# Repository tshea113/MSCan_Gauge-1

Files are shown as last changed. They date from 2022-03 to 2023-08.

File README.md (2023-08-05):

MSCan_Gauge
===========

This project uses a [Teensy 3.2 or 4.0 microcontroller](https://www.pjrc.com/teensy/index.html) to interface with a [Megasquirt open source standalone
engine controller](http://www.msextra.com/) via CAN bus. Data is received from the ECU and shown on a display that fits in a standard 52mm gauge pod.

Due to Teensy 3.2 availability, the project has been ported to work with [Teensy 4.0](https://www.pjrc.com/store/teensy40.html) which is both more powerful and more available. Highly suggest using that hardware over the Teensy 3.2.

## Demo
https://youtube.com/shorts/4NsZm0GjasA?feature=share

## Hardware used
* [Teensy 4.0 microcontroller](https://www.pjrc.com/store/teensy40.html)
* [Adafruit 128x64 monochrome 1.3" OLED display](http://www.adafruit.com/products/938) connected via SPI.
* [Adafruit rotary encoder](http://www.adafruit.com/products/377)

Unfortunately this display from Adafruit is pretty expensive compared to some of the cheaper no-name brands.
The gauge housing is fitted to work with this specific display model, but, although untested, any one of the SSD1306 driver controlled displays should work (as long as the screen is 128x64 pixels).

The rotary encoder is P/N: PEC11-4215F-S24 (or any substituteable encoder). If you are already ordering from Adafruit, it's best to just grab theirs.

## Libraries required
* [Metro](https://github.com/thomasfredericks/Metro-Arduino-Wiring) - event scheduling
* [Time](https://github.com/PaulStoffregen/Time) - onboard clock
* [FlexCAN_T4](https://github.com/tonton81/FlexCAN_T4) - CAN bus
* [SSD1306](https://github.com/adafruit/Adafruit_SSD1306) - OLED display
* [Adafruit GFX](https://github.com/adafruit/Adafruit-GFX-Library) - required by SSD1306
* [Adafruit BusIO](https://github.com/adafruit/Adafruit_BusIO) - I2C and SPI library (required by SSD1306)
* [EncoderTool](https://github.com/luni64/EncoderTool) - rotary encoder
* [Bounce2](https://github.com/thomasfredericks/Bounce2) - button debouncing

## Component BOM
Passives are 1206 package unless otherwise noted.
* R1 - 10K
* C1 - 10uF
* IC1 - SN65HVD230 (or similar) CAN transceiver
* VR1 - TSR 1-2450 DC/DC Converter (500mA may work but 1A is recommended)
* 2.54mm spacing male pin headers - standard length (5 male pins for OLED screen and 4 male pins for encoder)
* 2.54mm spacing female socket headers - standard length (2 banks of 14 female pins for the teensy)
* 8 way Molex Micro-fit+ connectors (Cable mount male and PCB mount female) and associated pins
* 5 and 4 position mating headers or connectors for OLED screen and encoder connections respectively

## Building the device

There are a lot of individual pieces that come together in this project, so it is best to test things as much as you can each step of the way. The gauge should come on when plugged into USB while external power is disconnected.
Before setting up CAN in your car, the gauge should still come on when the car is powered on and display a message about waiting for data. When you set up the CAN connection, you should start to see data come in on the screen.

### Software
You can use the released software to get a known working stable version. Install Teensyduino on your system and load the supplied hex file for your device. Plug in the teensy to your computer and press the program button on the Teensy and the software should be programmed.

If you would like to modify the code, you can build it yourself through Arduino IDE. You will need to install the listed libraries before building.

### PCB
Board gerber files are stored under Board files. Teensy 3.2 and Teensy 4.0 are *NOT* pin compatible, so choose the right PCB for your Teensy. Then encoder files are just for the rotary encoder which will be mounted remotely. I used OSHPark to build my boards, but there are plenty of PCB fabs out there to use.

The component BOM matches the labels on the PCB. You should be able to solder everything using a fine tip soldering iron. The CAN tranceiver is a little tricky, but doable.

### Housing
Highly recommended to print these out of ABS/ASA. I used PLA as a prototype and it *WILL* deform. Print the main housing using supports, but the PCB tray and the face should be able to just print flat on the print bed.

You will need the following fasteners:
* 8 M2 nuts
* 4 M2 bolts 6mm length
* 4 M2 bolts 10mm length

Fasten the PCB to the tray by placing 4 of the M2 nuts in the slots on the bottom. Use the shorter 6mm bolts to secure the PCB. The tray should slide right into the housing with the Molex connector coming out the back.
The tray may be tight at first, but sliding it in and out a few times should clearance it enough to be smooth.

Place 4 of the M2 Nuts into the back of the holes for the display mounts. Use a bolt to pull the nuts into their slots. Once they are in, they should be secure enough that they do not fall out.

To connect the display, you will need 5 female-to-female connectors. I used some pre-made 3 inch wires that have female header pins on the ends. Tuck the wires back into the gauge and place the screen into the slot.
Secure the display using the 10mm bolts. The gauge face should slot right into the housing.

### Car wiring
The wiring in the car should be wired up to the male Micro-fit+ connector. You will need to supply:
* 12V power
  * Preferably something that isn't hot while cranking.
  * This will probably be the same supply you use for other gauges like wideband.
* Ground
  * Nothing specific here, this isn't a sensor ground or anything.
* ENCG
  * This is the ground for the encoder. It should wire up to the corresponding pin on the encoder PCB.
* ENCB
  * This is the button pin for the encoder. It should wire up to the corresponding pin on the encoder PCB.
* ENC1
  * This is one of the direction pins for the encoder. It should wire up to the corresponding pin on the encoder PCB.
* ENC2
  * This is the other direction pin for the encoder. It should wire up to the corresponding pin on the encoder PCB.
* CANL
  * CAN low signal. This should wire up to the MegaSquirt.
* CANH
  * CAN high signal. This should wire up to the MegaSquirt.

CANL and CANH wires are a differential signal and should be twisted together coming from the ECU to whatever device you are connecting them to (in this case the gauge).

The CAN bus requires a 120Ohm termination at the end of the bus. I did not include this on the gauge, since other devices may already have this termination.
If this gauge is your only CAN device, you can use a Deutsh connector with this termination on the end:
* DTM06-2S-P006
  * This is the 120Ohm termination
* DTM04-2P
  * This is the female receptical.
  * You will also need pins and the little plastic bracket. Read more on Deutsch connectors to see what parts you need.

The Molex Micro-fit+ pins are very small and delicate. They do not require any special crimping tools, and I was able to use a generic pin crimping tool without issues. The pins should slot into the male housing and you will feel a click when they are secure.
If you aren't gentle with them, the wings on the end that secure the pins will get bent. To fix this, pull out the pin, carefully bend the wings back, and try again.

Connect the Molex connector to the gauge, and the gauge should come on when the ignition is in the ON position.

### Tunerstudio
You will need to configure CAN Realtime Data Broadcasting for the data you are interested in.
* Make sure the baseID is set to 1520.
* Data rate for each item will depend on how fast you expect the data to change. Things like coolant temp and MAT are going to be very slow while things like RPM and MAP are going to be faster.
* Be sure the master enable for CAN is set under CAN Paramteters
* Also enable CAN Broadcasting under CAN Broadcasting

## Future Development

There probably won't be any development on this project outside of bug fixes to make sure this stays in a good state.
I'm working on a new project that will allow me to fix some of the headaches with this design:
* Updating the diplay to use the GC9A01A circular LCD display.
  * LCDs are much easier to see in the sunlight and this display has RGB colors.
* Changing the project to use PlatformIO
  * This will allow the project to store libraries in GitHub. You will be able to sync the repo and build it directly!
  * I can use GitHub Actions to automate builds in the repo.
  * Lots of nice tools inside of PlatformIO IDE.
* Moving away from the Arduino style coding to something more C++ based.
  * Partially enabled by PlatformIO, since it just builds using CMake.
  * This project grew in scope enough where the lack of OOP was making it difficult to manage data & states.

New development will be under the teensy-CAN-gauge project: https://github.com/tshea113/teensy-CAN-gauge/

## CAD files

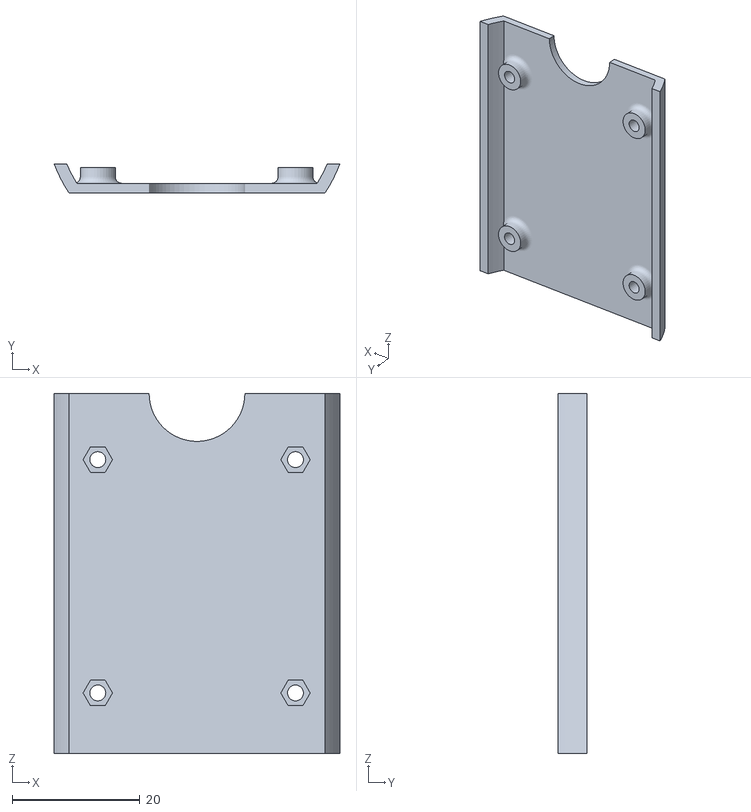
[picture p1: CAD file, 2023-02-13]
Housing files/PCB Plate.stl
44.8 x 4.50 x 56.4

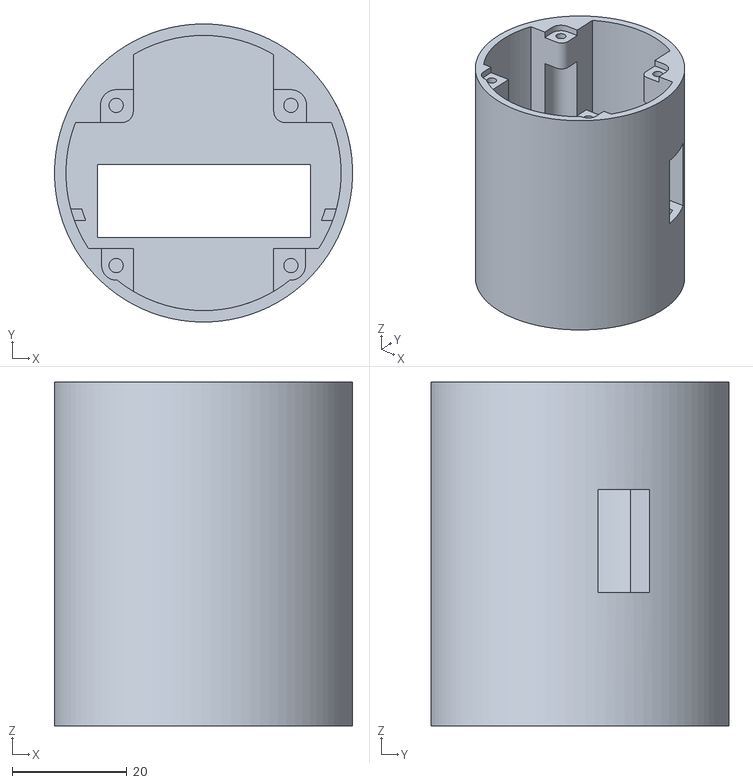
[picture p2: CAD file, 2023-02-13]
Housing files/Gauge Body.stl
52.0 x 52.0 x 60.0

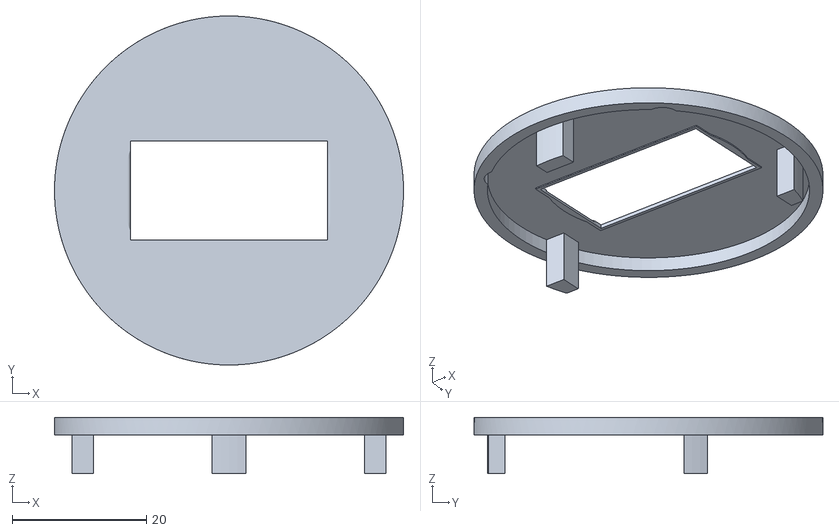
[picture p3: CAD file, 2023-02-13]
Housing files/LCD Faceplate.stl
52.0 x 52.0 x 8.40

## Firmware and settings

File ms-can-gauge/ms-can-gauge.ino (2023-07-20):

#include <Metro.h>
#include <FlexCAN_T4.h>
#include <Wire.h>
#include <Adafruit_GFX.h>
#include <Adafruit_SSD1306.h>
#include <TimeLib.h>
#include <EncoderTool.h>
#include <EEPROM.h>
#include <Bounce2.h>

#include "megasquirt-messages.h"
#include "pin-definitions.h"
#include "constants.h"
#include "gauge-data.h"

using namespace EncoderTool;

// Encoder
Encoder myEncoder;
Bounce2::Button encoderButton;
int encoder_index;

// FlexCAN
// Teensy 3.2 only has CAN0, but Teensy 4.0 has CAN1, CAN2, and CAN3, so we must
// set these up based upon the device for which we are compiling.
#if defined(__MK20DX256__) || defined(__MK64FX512__) // Teensy 3.2/3.5
  FlexCAN_T4<CAN0, RX_SIZE_256, TX_SIZE_16> myCan;
#endif
#if defined(__IMXRT1062__) // Teensy 4.0
  FlexCAN_T4<CAN2, RX_SIZE_256, TX_SIZE_16> myCan;
#endif

// OLED Display I2C
Adafruit_SSD1306 display(kOledWidth, kOledHeight, &Wire, OLED_RESET);

// Metro ticks are milliseconds
Metro commTimer = Metro(kCanTimeout);
Metro displayTimer = Metro(kDisplayRefresh);
boolean connection_state = false;

// MS data vars
GaugeData gaugeData;

// Menu vars
MenuState menuState;
Settings gaugeSettings;

static CAN_message_t txMessage,rxMessage;

msg_packed rxmsg_id,txmsg_id;
msg_req_data_raw msg_req_data;

unsigned long validity_window_highest; // for hi/low + histogram window update
unsigned long validity_window_lowest;

int histogram[64];
int histogram_index;

// -------------------------------------------------------------
void setup(void)
{
  // By default, we'll generate the high voltage from the 3.3v line internally! (neat!)
  display.begin(SSD1306_SWITCHCAPVCC, kScreenI2cAddress);

  // Show splashscreen
  display.clearDisplay();
  display.drawBitmap(0,0, miata_logo, 128, 64, 1);
  display.display();

  // On first run of the gauge, the EEPROM will have garbage values. To fix this,
  // we check that all values are written before starting.
  if (EEPROM.read(kEEPROMInitAddr) != kEEPROMValidId)
  {
    for(int i = EEPROM.read(kEEPROMInitAddr); i <= kEEPROMValidId; i++)
    {
      switch (i)
      {
      default:
        EEPROM.write(kWarningEnableAddr, gaugeSettings.warnings_enable);
        break;
      case 1:
        EEPROM.write(kCoolantWarningAddr, gaugeSettings.coolant_warning_temp);
        EEPROM.write(kCoolantWarningAddr + 1, gaugeSettings.coolant_warning_temp >> 8);
        break;
      }
    }
    EEPROM.write(kEEPROMInitAddr, kEEPROMValidId);
  }

  gaugeSettings.warnings_enable = EEPROM.read(kWarningEnableAddr);
  gaugeSettings.coolant_warning_temp = EEPROM.read((kCoolantWarningAddr + 1)) << 8;
  gaugeSettings.coolant_warning_temp |= EEPROM.read(kCoolantWarningAddr);

  if (kDebugMode)
  {
    Serial.print("Warnings Enable: ");
    Serial.println(gaugeSettings.warnings_enable);
    Serial.print("Coolant Warning: ");
    Serial.println(gaugeSettings.coolant_warning_temp);
  }

  myCan.begin();
  myCan.setBaudRate(kCanBaud);

  myEncoder.begin(ENC_PIN_1, ENC_PIN_2);
  encoderButton.attach(ENC_BUTTON, INPUT_PULLUP);
  encoderButton.interval(kButtonInterval);
  encoderButton.setPressedState(LOW);

  pinMode(LED_BUILTIN, OUTPUT);
  digitalWrite(LED_BUILTIN, HIGH);
  delay(500);
  digitalWrite(LED_BUILTIN, LOW);
}

// -------------------------------------------------------------
void loop(void)
{
  encoderButton.update();
  MenuCheck();

  // See if we have gotten any CAN messages in the last second. display an error if not
  if (commTimer.check() && !kDebugMode)
  {
    display.clearDisplay();
    display.setTextSize(1);
    display.setTextColor(WHITE);
    display.setCursor(0,56);
    display.println("Waiting for data...");
    display.setCursor(0,0);
    display.display();

    commTimer.reset();
    connection_state = false;
  }

  // main display routine
  if ((connection_state || kDebugMode) && displayTimer.check())
  {
    if (menuState.in_menu)
    {
      MenuView();
    }
    else if (menuState.in_settings)
    {
      SettingsView();
    }
    else
    {
      if (IsOutOfBounds() && gaugeSettings.warnings_enable)
      {
        WarningView();
      }
      else
      {
        switch (static_cast<ViewsMenu>(menuState.menu_position))
        {
        case kDashboardView:
          DashboardView();
          break;
        case kSingleView:
          SingleView();
          break;
        case kGraphView:
          GraphView();
          break;
        default:
          Serial.println("Invalid view!");
        }
      } 
    }
    display.display();
    displayTimer.reset();
  }

  // handle received CAN frames
  if (myCan.read(rxMessage) && !kDebugMode)
  {
    commTimer.reset();
    connection_state = true;

    ReadCanMessage();
  }
}

// Converts a value stored in the format (val)E-1 to a decimal string for display
String ToDecimal(int val)
{
  String temp = String(val);

  // Single digit values need a leading zero
  if (temp.length() == 1)
  {
    return "0." + temp.substring(0, temp.length());
  }
  else
  {
    return temp.substring(0, temp.length() - 1) + '.' + temp.charAt(temp.length() - 1);
  }
}

// Returns the number of characters in an integer
int IntegerWidth(int val, bool isDecimal)
{
  String temp = String(val);
  if (isDecimal)
  {
    // Single digit values need a leading zero
    if (temp.length() == 1)
    {
      return temp.length() + 2;
    }
    else
    {
      return temp.length() + 1;
    }
  }
  else
  {
    return temp.length();
  }
}

void ReadCanMessage()
{
  // ID's 1520+ are Megasquirt CAN broadcast frames
  switch (rxMessage.id)
  {
  case 1520: // 0
    gaugeData.rpm = (rxMessage.buf[6] << 8) | rxMessage.buf[7];
    break;
  case 1521: // 1
    gaugeData.spark_advance = (rxMessage.buf[0] << 8) | rxMessage.buf[1];
    gaugeData.engine = rxMessage.buf[3];
    gaugeData.afr_target = rxMessage.buf[4];
    break;
  case 1522: // 2
    gaugeData.barometer = (rxMessage.buf[0] << 8) | rxMessage.buf[1];
    gaugeData.map = (rxMessage.buf[2] << 8) | rxMessage.buf[3];
    gaugeData.mat = (rxMessage.buf[4] << 8) | rxMessage.buf[5];
    gaugeData.coolant_temp = (rxMessage.buf[6] << 8) | rxMessage.buf[7];
    // 6.895kpa = 1psi
    gaugeData.boost_psi = ((gaugeData.map - gaugeData.barometer) * 200) / 1379;
    break;
  case 1523: // 3
    gaugeData.tps = (rxMessage.buf[0] << 8) | rxMessage.buf[1];
    gaugeData.battery_voltage = (rxMessage.buf[2] << 8) | rxMessage.buf[3];
    break;
  case 1524: // 4
    gaugeData.knock = (rxMessage.buf[0] << 8) | rxMessage.buf[1];
    gaugeData.ego_correction = (rxMessage.buf[2] << 8) | rxMessage.buf[3];
    break;
  case 1526: // 6
    gaugeData.iac = (((rxMessage.buf[6] << 8) | rxMessage.buf[7]) * 49) / 125;
  case 1529: // 9
    gaugeData.dwell = (rxMessage.buf[4] << 8) | rxMessage.buf[5];
    break;
  case 1530: // 10
    gaugeData.status_1 = rxMessage.buf[0];
    gaugeData.status_2 = rxMessage.buf[1];
    gaugeData.status_3 = rxMessage.buf[2];
    gaugeData.status_6 = rxMessage.buf[6];
    gaugeData.status_7 = rxMessage.buf[7];
    break;
  case 1537: // 17
    gaugeData.boost_duty = (rxMessage.buf[4] << 8) | rxMessage.buf[5];
    break;
  case 1548: // 28
    gaugeData.idle_target = (rxMessage.buf[0] << 8) | rxMessage.buf[1];
    break;
  case 1551: // 31
    gaugeData.afr = rxMessage.buf[0];
    break;
  case 1574: // 54
    gaugeData.check_engine_light = rxMessage.buf[2];
    break;
  default: 
    // not a broadcast packet
    // assume this is a normal Megasquirt CAN protocol packet and decode the header
    if (rxMessage.flags.extended)
    {
      rxmsg_id.i = rxMessage.id;
      // is this being sent to us?
      if (rxmsg_id.values.to_id == kMyCanId)
      {
        switch (rxmsg_id.values.msg_type)
        {
        case 1: // MSG_REQ - request data
          // the data required for the MSG_RSP header is packed into the first 3 data bytes
          msg_req_data.bytes.b0 = rxMessage.buf[0];
          msg_req_data.bytes.b1 = rxMessage.buf[1];
          msg_req_data.bytes.b2 = rxMessage.buf[2];
          // Create the tx packet header
          txmsg_id.values.msg_type = 2; // MSG_RSP
          txmsg_id.values.to_id = kMsCanId; // Megasquirt CAN ID should normally be 0
          txmsg_id.values.from_id = kMyCanId;
          txmsg_id.values.block = msg_req_data.values.varblk;
          txmsg_id.values.offset = msg_req_data.values.varoffset;
          txMessage.flags.extended = 1;
          txMessage.id = txmsg_id.i;
          txMessage.len = 8;
          // Use the same block and offset as JBPerf IO expander board for compatibility reasons
          // Docs at http://www.jbperf.com/io_extender/firmware/0_1_2/io_extender.ini (or latest version)

          // realtime clock
          if (rxmsg_id.values.block == 7 && rxmsg_id.values.offset == 110)
          {
            /*
              rtc_sec          = scalar, U08,  110, "", 1,0
              rtc_min          = scalar, U08,  111, "", 1,0
              rtc_hour         = scalar, U08,  112, "", 1,0
              rtc_day          = scalar, U08,  113, "", 1,0 // not sure what "day" means. seems to be ignored...
              rtc_date         = scalar, U08,  114, "", 1,0
              rtc_month        = scalar, U08,  115, "", 1,0
              rtc_year         = scalar, U16,  116, "", 1,0
            */

            // only return clock info if the local clock has actually been set (via GPS or RTC)
            if (timeStatus() == timeSet)
            {
              txMessage.buf[0] = second();
              txMessage.buf[1] = minute();
              txMessage.buf[2] = hour();
              txMessage.buf[3] = 0;
              txMessage.buf[4] = day();
              txMessage.buf[5] = month();
              txMessage.buf[6] = year() / 256;
              txMessage.buf[7] = year() % 256;
              // send the message!
              myCan.write(txMessage);
            }
          } 
        }
      }
    }
    else
    {
      Serial.write("ID: ");
      Serial.print(rxMessage.id);
    }
  }
}

boolean IsOutOfBounds()
{
  if (gaugeData.rpm > 100)
  {
    if ((gaugeData.coolant_temp/10) > gaugeSettings.coolant_warning_temp) return true;
    if (bitRead(gaugeData.status_2,6)) return true; // overboost
  } 
  return false;
}

void MenuCheck()
{
  // Pressing the button brings up the menu or selects position
  if (encoderButton.pressed())
  {
    if (kDebugMode) Serial.println("Button pressed!");
    // Settings Menu
    if (menuState.in_settings)
    {
      if (menuState.is_setting_selected)
      {
        menuState.is_setting_selected = false;
        myEncoder.setLimits(0, kNumSettings - 1, true);
        myEncoder.setValue(menuState.settings_position);
      }
      else
      {
        menuState.is_setting_selected = true;
        switch (static_cast<SettingMenu>(menuState.settings_position))
        {
        case kWarningsEnableSetting:
          myEncoder.setLimits(0, 1, true);
          myEncoder.setValue(gaugeSettings.warnings_enable);
          break;
        case kCoolantWarningSetting:
          myEncoder.setLimits(0, kMaxCoolantTemp, true);
          myEncoder.setValue(gaugeSettings.coolant_warning_temp);
          break;
        case kExitSetting:
          menuState.settings_position = 0;
          menuState.in_settings = false;
          menuState.is_setting_selected = false;
          menuState.in_menu = true;
          myEncoder.setLimits(0, kNumViews - 1, true);
          myEncoder.setValue(menuState.menu_position);
          WriteSettingsToEEPROM();
          break;
        }
      }
    }
    // Views Menu
    else
    {
      if (menuState.in_menu)
      {
        menuState.in_menu = false;
        switch (static_cast<ViewsMenu>(menuState.menu_position))
        {
        case kDashboardView:
          break;
        case kSingleView:
          myEncoder.setLimits(0, kNumGauges - 1, true);
          myEncoder.setValue(menuState.gauge_single_position);
          break;
        case kGraphView:
          myEncoder.setLimits(0, kNumGraphs - 1, true);
          myEncoder.setValue(menuState.gauge_graph_position);
          break;
        case kSettingView:
          menuState.in_settings = true;
          myEncoder.setLimits(0, kNumSettings - 1, true);
          myEncoder.setValue(0);
          break;
        }
      }
      else
      {
        menuState.in_menu = true;
        myEncoder.setLimits(0, kNumViews - 1, true);
        myEncoder.setValue(menuState.menu_position);
      }
    }
  }
}

void WriteSettingsToEEPROM()
{
  if (gaugeSettings.dirty)
  {
    if (kDebugMode)
    {
      Serial.println("Writing to EEPROM!");
    }

    EEPROM.write(kWarningEnableAddr, gaugeSettings.warnings_enable);
    EEPROM.write(kCoolantWarningAddr, gaugeSettings.coolant_warning_temp);
    EEPROM.write(kCoolantWarningAddr + 1, gaugeSettings.coolant_warning_temp >> 8);
    gaugeSettings.dirty = false;

    if (kDebugMode)
    {
      Serial.println("Done writing to EEPROM!");
    }
  }
}

void MenuView()
{
  // Check for rotations
  if (myEncoder.valueChanged())
  {
    encoder_index = myEncoder.getValue();
    menuState.menu_position = encoder_index;

    if (kDebugMode)
    {
      Serial.print("Encoder: ");
      Serial.println(encoder_index);
      Serial.print("Menu: ");
      Serial.println(menuState.menu_position);
    }
  }

  display.clearDisplay();
  PrintMenu(kViews, kNumViews, menuState.menu_position);
  display.display();
}

void SettingsView()
{
  // Check for rotations
  if (myEncoder.valueChanged())
  {
    encoder_index=myEncoder.getValue();
    if (menuState.is_setting_selected)
    {
      switch (static_cast<SettingMenu>(menuState.settings_position))
      {
      case kWarningsEnableSetting:
        gaugeSettings.warnings_enable = encoder_index;
        break;
      case kCoolantWarningSetting:
        gaugeSettings.coolant_warning_temp = encoder_index;
        break;
      case kExitSetting:
        break;
      }
      gaugeSettings.dirty = true;      
    }
    else
    {
      menuState.settings_position = encoder_index;
    }

    if (kDebugMode)
    {
      Serial.print("Encoder: ");
      Serial.println(encoder_index);
      Serial.print("Settings: ");
      Serial.println(menuState.settings_position);
    }
  }

  display.clearDisplay();

  display.setTextSize(1);
  for (int i = 0; i < kNumSettings; i++)
  {
    if (menuState.settings_position == i && !menuState.is_setting_selected)
    {
      display.setTextColor(BLACK, WHITE);
    }
    else
    {
      display.setTextColor(WHITE);
    }

    display.setCursor(2, (10 * i) + 2);
    display.print(kSettings[i]);

    if (menuState.settings_position == i && menuState.is_setting_selected)
    {
      display.setTextColor(BLACK, WHITE);   
    }
    else
    {
      display.setTextColor(WHITE);       
    }

    display.setCursor(100, (10 * i) + 2);
    switch (static_cast<SettingMenu>(i))
    {
    case kWarningsEnableSetting:
      display.print(gaugeSettings.warnings_enable ? "On" : "Off"); 
      break;
    case kCoolantWarningSetting:
      display.print(gaugeSettings.coolant_warning_temp);
      break;
    case kExitSetting:
      break;
    }
  }

  display.display();
}

void WarningView()
{
  int dlength;
  int midpos;

  display.clearDisplay();

  if ((gaugeData.coolant_temp/10) > gaugeSettings.coolant_warning_temp)
  {
    display.setTextColor(WHITE);
    display.setTextSize(2);
    display.setCursor(0, 0);
    display.print("WARNING");

    dlength = 3;
    midpos = (63 - ((dlength * 23) / 2));
    display.setCursor(midpos, 16);
    display.setTextSize(4);
    display.print(gaugeData.coolant_temp / 10);

    display.setTextSize(2);
    display.setCursor(0, 48);
    display.print("CLT");
  }

  display.display();
}

void DashboardView()
{
  display.clearDisplay();

  display.setTextColor(WHITE);

  int16_t labelXBound = 0;
  int16_t labelYBound = 0;
  uint16_t labelWidth = 0;
  uint16_t labelHeight = 0;

  // Dashboard Line 1
  // RPM
  display.setTextSize(1);
  display.getTextBounds(kDashboardItems[0], 0, 0, &labelXBound, &labelYBound, &labelWidth, &labelHeight);
  display.setCursor(0, (kDashboardLineHeight - 1) - labelHeight);
  display.print(kDashboardItems[0]);

  display.setTextSize(2);
  display.setCursor(labelWidth + 2, 1);
  display.println(gaugeData.rpm);

  // Dashboard Line 2
  // AFR
  display.setTextSize(1);
  display.getTextBounds(kDashboardItems[1], 0, 0, &labelXBound, &labelYBound, &labelWidth, &labelHeight);
  display.setCursor(0, ((2 * kDashboardLineHeight) - 1) - labelHeight);
  display.print(kDashboardItems[1]);

  display.setTextSize(2);
  display.setCursor(labelWidth + 2, kDashboardLineHeight + 1);
  display.print(ToDecimal(gaugeData.afr));

  // CLT
  display.setTextSize(1);
  display.getTextBounds(kDashboardItems[2], kDashboardColumnWidth, 0, &labelXBound, &labelYBound, &labelWidth, &labelHeight);
  display.setCursor(kDashboardColumnWidth, ((2 * kDashboardLineHeight) - 1) - labelHeight);
  display.print(kDashboardItems[2]);

  display.setTextSize(2);
  display.setCursor(kDashboardColumnWidth + (labelWidth + 2), kDashboardLineHeight + 1);
  display.print(gaugeData.coolant_temp / 10);

  // Dashboard Line 3
  // In boost, show boost psi, otherwise show MAT.
  if (gaugeData.map > gaugeData.barometer)
  {
    // PSI
    display.setTextSize(1);
    display.getTextBounds(kDashboardItems[5], 0, 0, &labelXBound, &labelYBound, &labelWidth, &labelHeight);
    display.setCursor(0, (2 * kDashboardLineHeight) + 1);
    display.print(kDashboardItems[5]);

    display.setTextSize(2);
    display.setCursor(labelWidth + 2, (2 * kDashboardLineHeight) + 1);
    // 6.895kpa = 1psi
    display.print(ToDecimal(gaugeData.boost_psi));
  }
  else
  {
    // MAT
    display.setTextSize(1);
    display.getTextBounds(kDashboardItems[4], 0, 0, &labelXBound, &labelYBound, &labelWidth, &labelHeight);
    display.setCursor(0, (2 * kDashboardLineHeight) + 1);
    display.print(kDashboardItems[4]);

    display.setTextSize(2);
    display.setCursor(labelWidth + 2, (2 * kDashboardLineHeight) + 1);
    display.print(gaugeData.mat / 10);
  }

  // MAP
  display.setTextSize(1);
  display.getTextBounds(kDashboardItems[3], kDashboardColumnWidth, 0, &labelXBound, &labelYBound, &labelWidth, &labelHeight);
  display.setCursor(kDashboardColumnWidth, (2 * kDashboardLineHeight) + 1);
  display.print(kDashboardItems[3]);

  display.setTextSize(2);
  display.setCursor(kDashboardColumnWidth + (labelWidth + 2), (2 * kDashboardLineHeight) + 1);
  display.print(gaugeData.map / 10);

  BottomView();
  display.display();
}

void BottomView()
{
  // Conditions for lighting up the menu items
  bool highlightItem[kNumBottomMenuItems];
  highlightItem[0] = gaugeData.check_engine_light != 0;
  highlightItem[1] = bitRead(gaugeData.status_6,6) == 1;
  highlightItem[2] = bitRead(gaugeData.status_2,7) == 1;
  highlightItem[3] = bitRead(gaugeData.status_7,4) == 1;
  highlightItem[4] = bitRead(gaugeData.status_2,6) == 1;
  highlightItem[5] = bitRead(gaugeData.engine,3) == 1;

  display.setTextSize(1);

  for (int i = 0; i < kNumBottomMenuItems; i++)
  {
    if (highlightItem[i])
    {
      display.setTextColor(BLACK, WHITE);
      display.fillRect(i * (kBottomMenuWidth - 1), ((kOledHeight - 1) - kBottomMenuHeight), kBottomMenuWidth, kBottomMenuHeight, WHITE);
    }
    else
    {
      display.setTextColor(WHITE);
      display.drawRect(i * (kBottomMenuWidth - 1), ((kOledHeight - 1) - kBottomMenuHeight), kBottomMenuWidth, kBottomMenuHeight, WHITE);
    }
    display.setCursor((i * (kBottomMenuWidth - 1)) + 2, (kOledHeight - kBottomMenuHeight) + 1);
    display.print(kBottomMenuItems[i]);
  }
}
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

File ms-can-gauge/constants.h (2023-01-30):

#include <avr/pgmspace.h>

// User configuerable constants
const int  kMyCanId      = 10;     // CAN ID of this unit
const int  kMsCanId      = 0;      // CAN ID of the Megasquirt (should almost always be 0)
const bool kDebugMode    = false;  // Debug mode for testing menus, screens, etc.

// Constants
const uint8_t kScreenI2cAddress           = 0x3D;   // I2C address of the OLED screen
const int     kCanTimeout                 = 1000;   // Display an error message if no CAN data during this interval
const int     kDisplayRefresh             = 100;    // Refresh the display at this interval
const int     kLedFlashTimer              = 1;      // How long to flash the led upon CAN frame receive/transmit
const int     kGaugeFlashTimer            = 50;     // Blink the led ring pixels during certain conditions
const int     kNumLeds                    = 16;     // Number of LEDs on the NeoPixel ring
const int     kDebounceTime               = 25;     // Debouncing Time - 150 is good, 200 is better, 250 seems worse
const int     kCanBaud                    = 500000; // CAN baud rate
const int     kMsDataNameMaxLength        = 10;     // Maximum length of MS data field name
const int     kMsDataBinNameMaxLength     = 14;     // Maximum length of MS data field name
const int     kButtonInterval             = 10;     // Button debounce time in ms
const int     kMinMaxGaugeInterval        = 30000;  // Reset interval for min/max gauge values in ms

// Display Constants
const int     kOledHeight                 = 64;     // Height of the OLED screen in pixels
const int     kOledWidth                  = 128;    // Width of the OLED screen in pixels
const int     kBottomMenuHeight           = 11;     // Height of the dashboard bottom menu in pixels
const int     kBottomMenuWidth            = 21;     // Width of each item in the dashboard bottom menu
const int     kDashboardLineHeight        = 17;     // Height of the dashboard lines in pixels
const int     kDashboardColumnWidth       = 72;     // Width of the dashboard column

// Settings Constraints
const int kMinRpm          = 5000;    // Minimum RPM for shift light setting
const int kMaxRpm          = 9900;    // Maximum RPM for shift light setting
const int kRpmInterval     = 100;     // Smallest interval for shift light setting
const int kMaxCoolantTemp  = 300;     // Maximum coolant temp for warning

enum TextWidth : int
{
  kTextWidth1 = 6,
  kTextWidth2 = 12,
  kTextWidth3 = 18,
  kTextWidth4 = 24
};

enum TextHeight : int
{
  kTextHeight1 = 8,
  kTextHeight2 = 16,
  kTextHeight3 = 24,
  kTextHeight4 = 32
};
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

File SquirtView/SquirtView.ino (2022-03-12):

#include <Metro.h>
#include <FlexCAN_T4.h>
#include <Wire.h>
#include <Adafruit_GFX.h>
#include <Adafruit_SSD1306.h>
#include <TimeLib.h>
#include <FastLED.h>
#include <EncoderTool.h>
#include <EEPROM.h>

#include "MegasquirtMessages.h"
#include "definitions.h"
#include "constants.h"
#include "GaugeData.h"

using namespace EncoderTool;

// FastLED
CRGB leds[NUM_LEDS];

// Encoder
Encoder myEnc;
int16_t encoderIndex;
bool buttonPressed;
volatile unsigned long last_millis;   //switch debouncing

// FlexCAN
// Teensy 3.2 only has CAN0, but Teensy 4.0 has CAN1, CAN2, and CAN3, so we must
// set these up based upon the device for which we are compiling.
#if defined(__MK20DX256__) || defined(__MK64FX512__) // Teensy 3.2/3.5
  FlexCAN_T4<CAN0, RX_SIZE_256, TX_SIZE_16> myCan;
#endif
#if defined(__IMXRT1062__) // Teensy 4.0
  FlexCAN_T4<CAN2, RX_SIZE_256, TX_SIZE_16> myCan;
#endif

// OLED Display I2C
Adafruit_SSD1306 display(SCREEN_WIDTH, SCREEN_HEIGHT, &Wire, OLED_RESET);

// Metro ticks are milliseconds
Metro commTimer = Metro(CAN_TIMEOUT);
Metro displayTimer = Metro(DISPLAY_REFRESH);
Metro ledTimer = Metro(LED_FLASH_TIMER);
Metro gaugeBlinkTimer = Metro(GAUGE_FLASH_TIMER);
boolean connectionState = false;
boolean gaugeBlink = false;

//MS data vars
GaugeData gaugeData;

// Menu vars
MenuState menuState;
Settings gaugeSettings;

byte neo_brightness = 1;
byte g_textsize = 1;
char tempchars[11];

static CAN_message_t txmsg,rxmsg;

msg_packed rxmsg_id,txmsg_id;
msg_req_data_raw msg_req_data;

unsigned long validity_window; // for hi/low + histogram window update
unsigned long validity_window2;

byte histogram[64]; // 512 memory usage
byte histogram_index;

// -------------------------------------------------------------
static void LedBlink()
{
  ledTimer.reset();
  digitalWrite(TEENSY_LED, 1);
}

// -------------------------------------------------------------
void setup(void)
{
  pinMode(TEENSY_LED, OUTPUT);
  digitalWrite(TEENSY_LED, 1);

  // On first run of the gauge, the EEPROM will have garbage values. To fix this,
  // we check that all values are written before starting.
  if (EEPROM.read(kEEPROMInitAddr) != kEEPROMValidId)
  {
    for(uint8_t numSettings = EEPROM.read(kEEPROMInitAddr); numSettings <= kEEPROMValidId; numSettings++)
    {
      switch (numSettings)
      {
      default:
        EEPROM.write(kRingEnableAddr, gaugeSettings.LEDRingEnable);
        break;
      case 1:
        EEPROM.write(kShiftRpmAddr, gaugeSettings.shiftRPM);
        EEPROM.write(kShiftRpmAddr + 1, gaugeSettings.shiftRPM >> 8);
        break;
      case 2:
        EEPROM.write(kWarningEnableAddr, gaugeSettings.warningsEnable);
        break;
      case 3:
        EEPROM.write(kCoolantWarningAddr, gaugeSettings.coolantWarning);
        EEPROM.write(kCoolantWarningAddr + 1, gaugeSettings.coolantWarning >> 8);
      }
    }
    EEPROM.write(kEEPROMInitAddr, kEEPROMValidId);
  }

  gaugeSettings.LEDRingEnable = EEPROM.read(kRingEnableAddr);
  gaugeSettings.shiftRPM = EEPROM.read((kShiftRpmAddr + 1)) << 8;
  gaugeSettings.shiftRPM |= EEPROM.read(kShiftRpmAddr);
  gaugeSettings.warningsEnable = EEPROM.read(kWarningEnableAddr);
  gaugeSettings.coolantWarning = EEPROM.read((kCoolantWarningAddr + 1)) << 8;
  gaugeSettings.coolantWarning |= EEPROM.read(kCoolantWarningAddr);

  if (DEBUG_MODE)
  {
    Serial.print("LED Ring Enable: ");
    Serial.println(gaugeSettings.LEDRingEnable);
    Serial.print("Shift RPM: ");
    Serial.println(gaugeSettings.shiftRPM);
    Serial.print("Warnings Enable: ");
    Serial.println(gaugeSettings.warningsEnable);
    Serial.print("Coolant Warning: ");
    Serial.println(gaugeSettings.coolantWarning);
  }

  myCan.begin();
  myCan.setBaudRate(CAN_BAUD);

  // Set encoder pins as input with internal pull-up resistors enabled
  pinMode(RBUTTON_INT, INPUT);
  digitalWrite(RBUTTON_INT, HIGH);
  attachInterrupt(RBUTTON_INT, DebounceIRQ, FALLING);

  // By default, we'll generate the high voltage from the 3.3v line internally! (neat!)
  display.begin(SSD1306_SWITCHCAPVCC, SCREEN_I2C_ADDR);

  // Show splashscreen
  display.clearDisplay();
  display.drawBitmap(0,0, miata_logo, 128, 64, 1);
  display.display();

  FastLED.addLeds<NEOPIXEL, LEDPIN>(leds, NUM_LEDS);

  // Ring initialization animation
  if (gaugeSettings.LEDRingEnable)
  {
    for(int i = 0; i < NUM_LEDS; i++)
    {
      leds[i].setRGB(16,16,16);
      FastLED.show();
      delay(20);
    }
    delay(200);
    // TODO: Don't like this magic number, maybe have this tied to some brightness variable?
    for (int j = 16; j > -1; j--) 
    {
      for(int i = 0; i < NUM_LEDS; i++)
      {
        leds[i].setRGB(j, j, j);
      }
      FastLED.show();
      delay(20);
    }
  }

  myEnc.begin(ENC_PIN_1, ENC_PIN_2);
  buttonPressed = false;

  delay(1000);
  digitalWrite(TEENSY_LED, 0);
}

// -------------------------------------------------------------
void loop(void)
{
  if (ledTimer.check() && digitalRead(TEENSY_LED))
  {
    digitalWrite(TEENSY_LED, 0);
    ledTimer.reset();
  }
  if (gaugeBlinkTimer.check())
  {
    gaugeBlink = !gaugeBlink;
    gaugeBlinkTimer.reset();
  }

  // See if we have gotten any CAN messages in the last second. display an error if not
  if (commTimer.check() && !DEBUG_MODE)
  {
    display.clearDisplay();
    display.setTextSize(1);
    display.setTextColor(WHITE);
    display.setCursor(0,56);
    display.println("Waiting for data...");
    display.setCursor(0,0);
    display.display();

    NoLightView();
    commTimer.reset();
    connectionState = false;
  }

  // main display routine
  if ((connectionState && displayTimer.check()) || DEBUG_MODE)
  {
    MenuCheck();

    if (gaugeSettings.LEDRingEnable)
    {
      ShiftLightView();
    }
    else
    {
      NoLightView();
    }

    if (menuState.inMenu)
    {
      MenuView();
    }
    else if (menuState.inSettings)
    {
      SettingsView();
    }
    else
    {
      if (IsOutOfBounds() && gaugeSettings.warningsEnable)
      {
        WarningView();
      }
      else
      {
        switch (static_cast<ViewsMenu>(menuState.menuPos))
        {
        case kDashboardView:
          DashboardView();
          break;
        case kSingleView:
          SingleView();
          break;
        case kGraphView:
          GraphView();
          break;
        default:
          Serial.println("Invalid view!");
        }
      } 
    }
    display.display();
    displayTimer.reset();
  }

  // handle received CAN frames
  if (myCan.read(rxmsg) && !DEBUG_MODE)
  {
    commTimer.reset();
    connectionState = true;
    LedBlink();

    ReadCanMessage();
  }
}
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

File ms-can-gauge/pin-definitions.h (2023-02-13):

// Pin definitions
#define ENC_BUTTON  15  //  
#define ENC_PIN_1   16  //  
#define ENC_PIN_2   17  // 
#define TEENSY_LED  13  // Onboard LED on the Teensy
#define OLED_RESET  20  // OLED Reset

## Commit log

2022-01-29 Remove GPS and Accel from PCB
    [teensy_ms.brd, teensy_ms.sch]
2022-02-08 Move arduino file for ide
2022-02-19 fix init animation brightness
    [SquirtView.ino]
2022-02-24 change neopixel to led ring
2022-02-28 small fixes from last branch
    [SquirtView.ino, constants.h]
2022-03-02 Add fusion360 files
    [teensy_ms.brd, teensy_ms.sch]
2022-03-06 Change folder from fusion360 to board
2022-03-12 Style and tech debt fixes
    [GaugeData.h, SquirtView.ino]
2022-03-15 change button debounce to library
2022-03-15 fix names that were off screen
    [gauge-data.h]
2022-03-15 Update single gauge printing
2022-10-23 fix the iac logic
    [ms-can-gauge.ino]
2023-01-28 add pcb gerber files and remove f3d file
2023-02-05 Fix highest value width issue
    [ms-can-gauge.ino]
2023-02-05 Fix data casting for can messages
    [gauge-data.h, ms-can-gauge.ino]
2023-02-12 Add gauge housing
    [Gauge Body.stl, LCD Faceplate.stl, PCB Plate.stl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]
2023-02-12 remove LED pins from boards
2023-02-12 Remove led code
2023-02-12 remove led ring stuff from readme
2023-02-12 Fix faceplate
    [LCD Faceplate.stl]
2023-07-15 Update boards with latest revision
2023-07-15 Remove old boards
